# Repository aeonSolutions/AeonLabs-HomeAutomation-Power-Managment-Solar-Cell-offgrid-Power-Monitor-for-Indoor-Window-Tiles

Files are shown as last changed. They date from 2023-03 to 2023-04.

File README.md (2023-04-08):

[PCB-Prototyping-Catalogue](https://github.com/aeonSolutions/PCB-Prototyping-Catalogue)  >>  [Home-Automation](https://github.com/aeonSolutions/PCB-Prototyping-Catalogue/tree/main/Home-Automation)  >>  [Smart Home Solar Power Management](https://github.com/aeonSolutions/PCB-Prototyping-Catalogue/tree/main/Home-Automation/Smart%20Home%20Solar%20Power%20Management)  >>   Solar Cell Tiles Power Monitor for Indoor Windows

<br>


  
 
 

<a href="https://trackgit.com">
trackgit-views
</a>


<br />

# Solar Cell Tiles Power Monitor for Indoor Windows

This is a simple PCB for a direct fit on commercially available [blue solar cell tiles](https://s.click.aliexpress.com/e/_DCnJW0V)  with dimensions 124x124mm. This Smart Device is intended to connected with the [Single Solar Cell with one 18650 Battery Storage](https://github.com/aeonSolutions/AeonLabs-HomeAutomation-Power-Managment-Single-SolarCELL-18650-battery-storage/blob/main/README.md) and also the [Single Solar Cell with two 18650 as Battery Storage](https://github.com/aeonSolutions/AeonLabs-HomeAutomation-Power-Managment-Single-SolarCELL-2X-18650-battery-storage/blob/main/README.md) to do active solar cell tile and battery management up to 8 solar tiles conencted together intended for indoor usage. In particular to be installed on the top or downside of transparent glass windows at a home or office. This PCB, when assembled with a blue solar cell tile, can be used to power a low voltage 4.2V indoor illumination network using ultra-low power micro LED strips.  For insatnce [this one](https://s.click.aliexpress.com/e/_DCKg9xJ) sold on AliExpress.   

When connected in series and installed on several windows and networked, can power off the grid a 4.2V LED illumination on all rooms and compartments at a home or office. During evenings and at night until bedtime. If one intends to use it to power indoors LED illumination during the day is required a High Capacity Power Bank connected to all first tiles of all the series. For instance this [power bank](https://s.click.aliexpress.com/e/_Ddl7nsh) here. 

One important take way about this prototype project is in the ability to be installed on any traditional apartment or home in a big city, requiring  124mm of window glass estate, at the top or at the bottom. And it can connect to existing home automation network or systems. 

<p align="center">
<a href="https://s.click.aliexpress.com/e/_DCnJW0V">

</a>
</p>

A breif view of specifications:

- up to 8 solar cell tiles battery active monitoring 
- Buzzer for sound alarm and warnings
- Onboard Temperature and humidity sensores
- Onboard motion sensor
- PCB asssembly in series made with a 10 pin pin header/ socket. For "plug and play" type of instalations
- Screw terminal to connect main low power 5V DC line at home/office. 

<br>

**Status**

waiting to be tested. Stay tuned for updates.

<br>

## PCB

<p align="center">
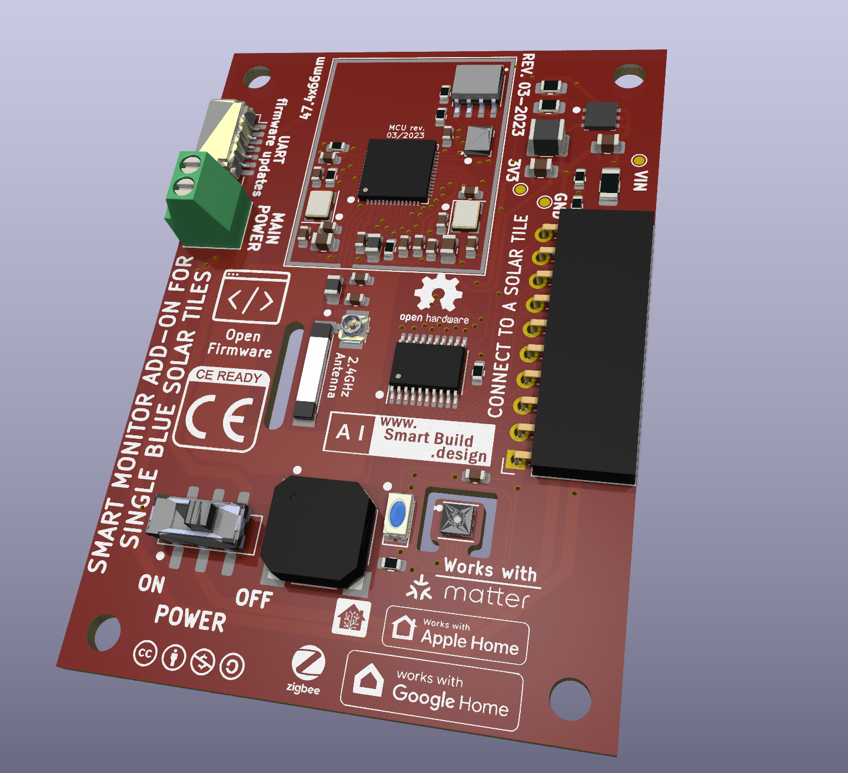
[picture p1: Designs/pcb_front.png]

</p>

<br>

## Compatibility

<p align="center">
 <a href"https://www.apple.com/shop/accessories/all/homekit">

 </a>
<a href="https://home.google.com"> 
 
 </a>
<a href="https://www.home-assistant.io">  
 
 </a>
<a href="https://csa-iot.org/all-solutions/matter/">  
 
 </a>
<a href="https://csa-iot.org/all-solutions/matter/">  
 
 </a>
</p>

<br>

## What one additionally needs
-  home tools
-  [transparent double sided tape](https://s.click.aliexpress.com/e/_DDJxMmD)
-  [blue solar cell tiles](https://s.click.aliexpress.com/e/_DCnJW0V)
-  [ultra-low power micro LED strips](https://s.click.aliexpress.com/e/_DCKg9xJ) 
-  [ultra-low power  LED Cob strips](https://s.click.aliexpress.com/e/_DnqkC4N)
-  [Nylon Guide for Electric Cable](https://s.click.aliexpress.com/e/_DBc1oVX)
-  [NCR18650B 3.7V 3400 mah 18650 Lithium](https://s.click.aliexpress.com/e/_DCh1sw1)
-  [Low power electrical wire](https://s.click.aliexpress.com/e/_DB1T3eN)
-  [16A Electrical Plug Wall Socket 110~250V Dual USB 2000mA Port](https://s.click.aliexpress.com/e/_DlVz3sh)
-  [Soldering iron](https://s.click.aliexpress.com/e/_DnDN8x3)
-  [Solder](https://s.click.aliexpress.com/e/_DlXtKMN)
- [power bank](https://s.click.aliexpress.com/e/_Ddl7nsh) 

<br />
<br />

## Author

You can get in touch with me on my LinkedIn Profile:

#### Miguel Tomas



You can also follow my GitHub Profile to stay updated about my latest projects: 

<br>

### Be supportive of my dedication and work towards technology education and buy me a cup of coffee
The PCB Desgin Files i provide here for anyone to use are free. If you like this Smart Device or use it, please consider buying me a cup of coffee, a slice of pizza or a book to help me study, eat and think new PCB design files.

[](https://www.buymeacoffee.com/migueltomas)

<br />

### Make a donation on Paypal
Make a donation on paypal and get a TAX refund*.

(http://paypal.me/mtpsilva)

<br>

### Support all these open hardware projects and become a patreon  
Liked any of my PCB KiCad Designs? Help and Support my open work to all by becomming a LDAD Patreon.
In return I will give a free PCB design in KiCad to all patreon supporters. To learn more go to patreon.com. Link below.

(https://www.patreon.com/ldad)

<br />
<br />

______________________________________________________________________________________________________________________________
### License
Before proceeding to download any of AeonLabs software solutions for open-source development and/or PCB hardware electronics development make sure you are choosing the right license for your project. See [AeonLabs Solutions for Open Hardware & Source Development](https://github.com/aeonSolutions/PCB-Prototyping-Catalogue/wiki/AeonLabs-Solutions-for-Open-Hardware-&-Source-Development) for more information.

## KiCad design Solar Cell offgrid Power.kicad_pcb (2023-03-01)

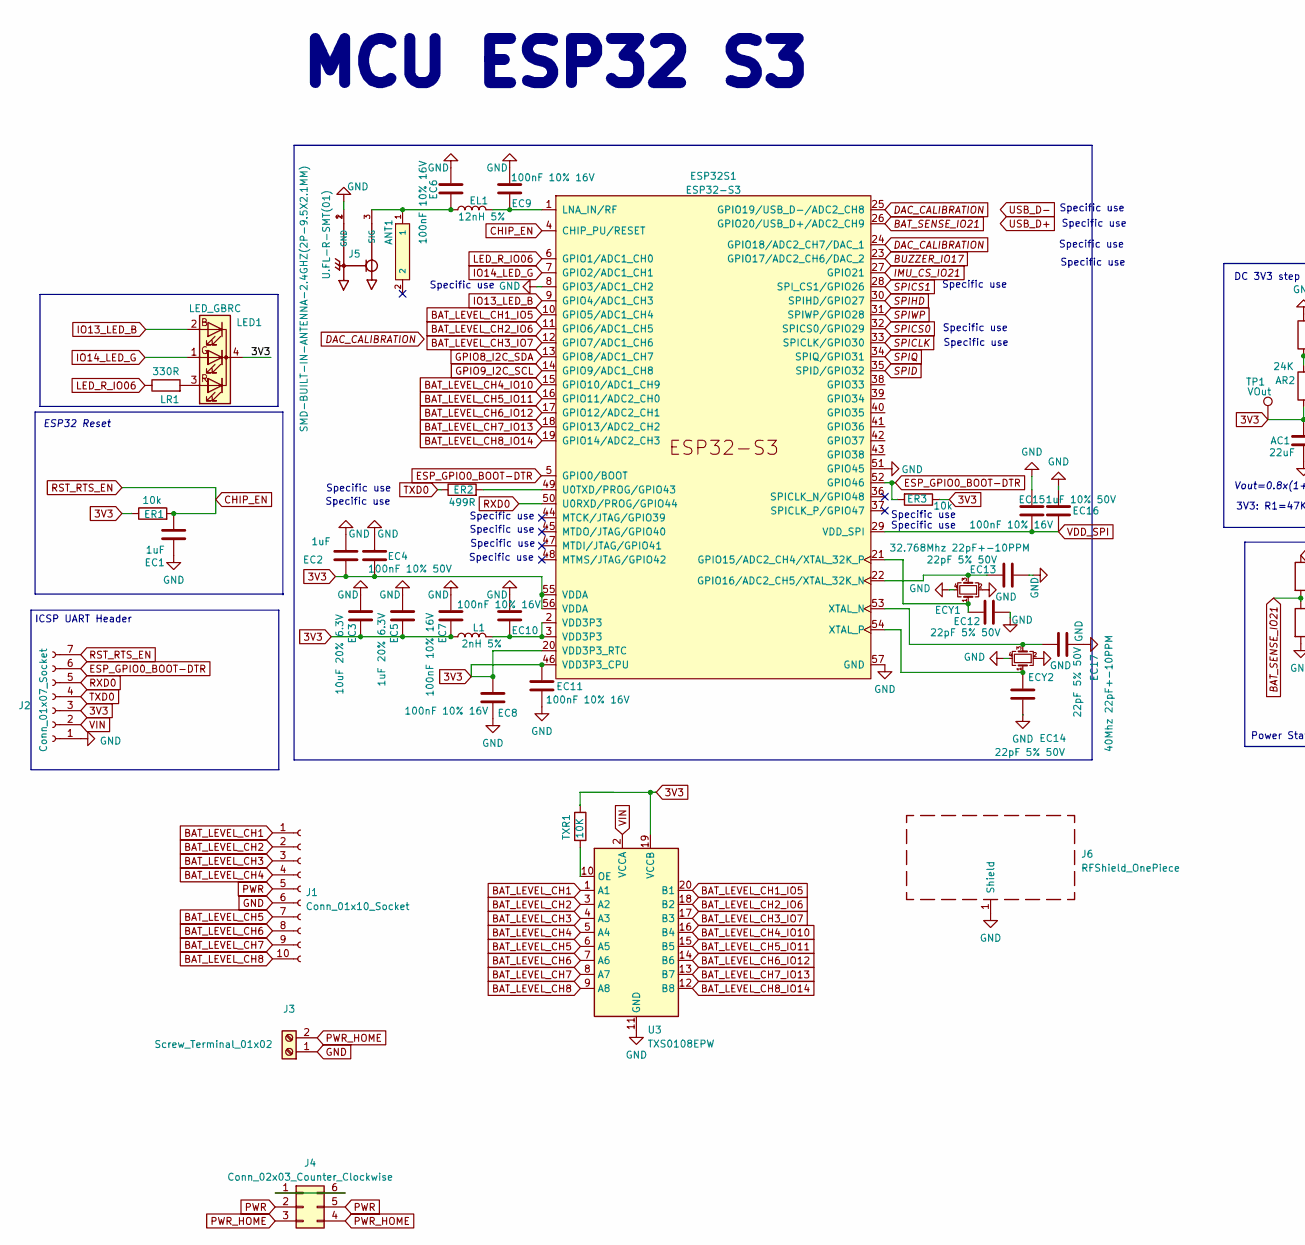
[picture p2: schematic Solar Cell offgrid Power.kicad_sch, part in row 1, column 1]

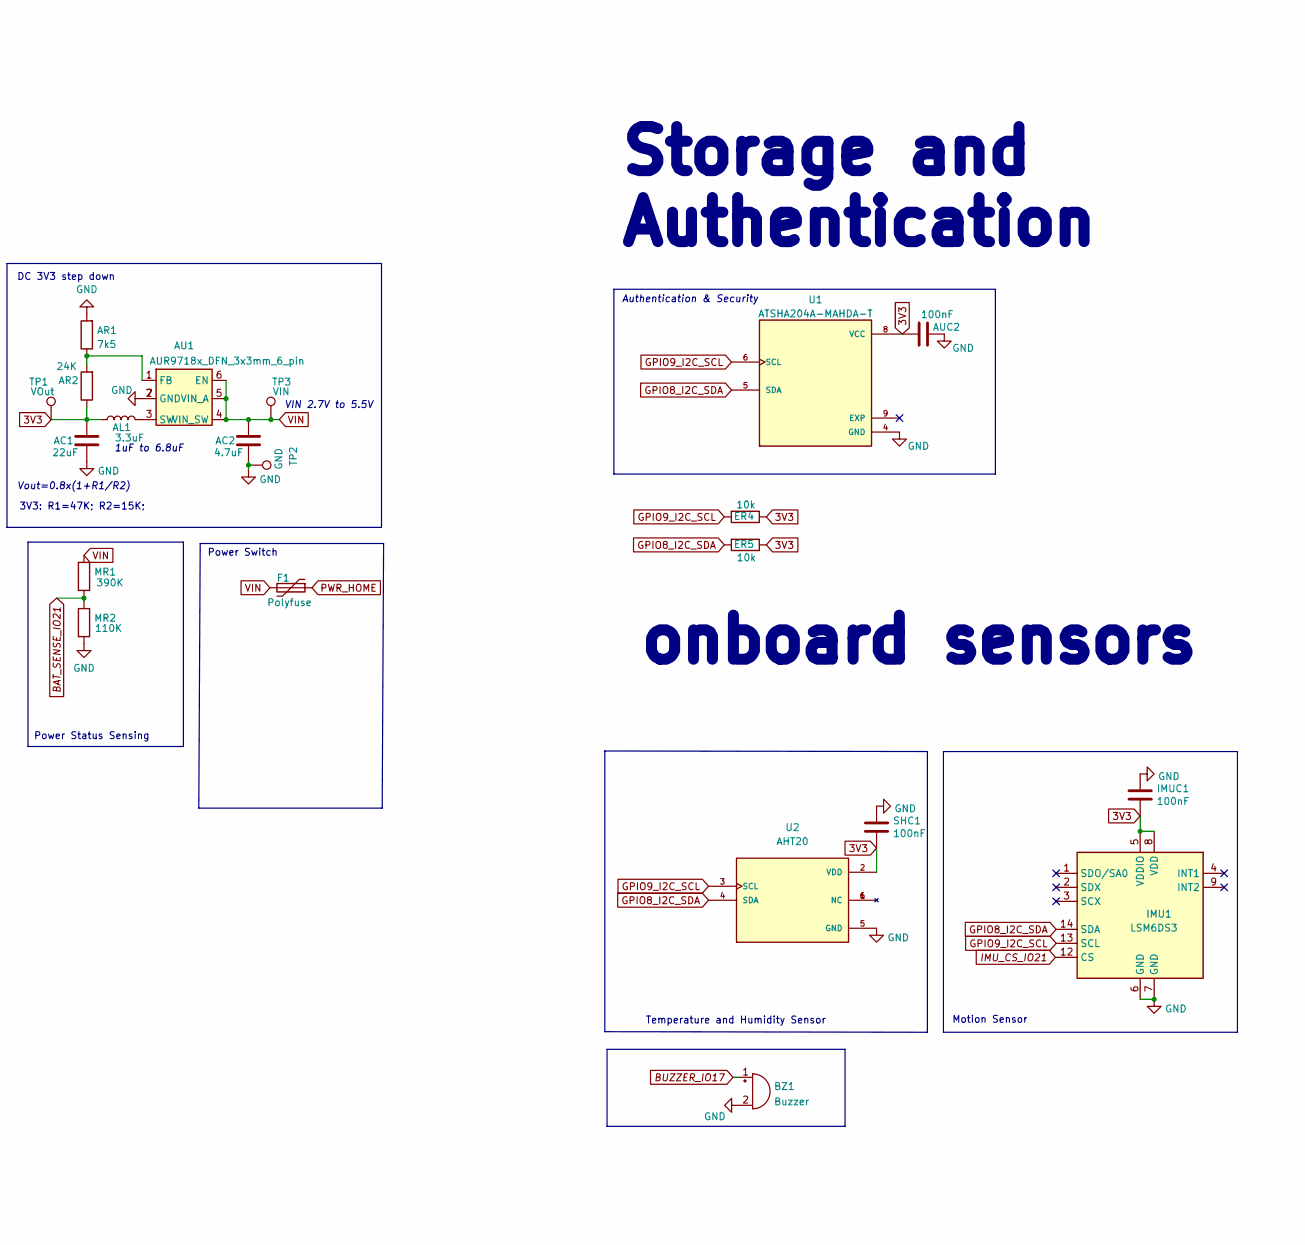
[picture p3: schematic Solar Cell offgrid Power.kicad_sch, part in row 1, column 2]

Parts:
AC1: 22uF; C_0805_2012Metric_Pad1.18x1.45mm_HandSolder
AC2: 4.7uF; C_0805_2012Metric_Pad1.18x1.45mm_HandSolder
AL1: 3.3uF; L_1210_3225Metric
ANT1: SMD-BUILT-IN-ANTENNA-2.4GHZ(2P-9.5X2.1MM); 2.4ghZ WIFI ANTENNA AN9520_ANT2-SMD-9.5X2.1X1.0MM
AR1: 7k5; R_0805_2012Metric_Pad1.20x1.40mm_HandSolder
AR2: 24K; R_0805_2012Metric_Pad1.20x1.40mm_HandSolder
AU1: AUR9718x_DFN_3x3mm_6_pin; AUR9718 ST1S09 SON95P300X300X100-7N
AUC2: 100nF; C_0603_1608Metric
BZ1: Buzzer; MagneticBuzzer_Kobitone_254-EMB84Q-RO
EC1: 1uF; C_0603_1608Metric
EC2: 1uF; C_0805_2012Metric
EC3: 10uF 20% 6.3V; C_0805_2012Metric
EC4: 100nF 10% 50V; C_0603_1608Metric
EC5: 1uF 20% 6.3V; C_0603_1608Metric
EC6, EC7, EC8, EC9, EC10, EC11, EC15: 100nF 10% 16V; C_0603_1608Metric
EC12, EC13, EC14, EC17: 22pF 5% 50V; C_0603_1608Metric
EC16: 1uF 10% 50V; C_0603_1608Metric
ECY1: 32.768Mhz 22pF+-10PPM; Crystal_SMD_EuroQuartz_MT-4Pin_3.2x2.5mm
ECY2: 40Mhz 22pF+-10PPM; Crystal_SMD_EuroQuartz_MT-4Pin_3.2x2.5mm
EL1: 12nH 5%; L_0805_2012Metric
ER1, ER3, ER4, ER5: 10k; R_0603_1608Metric
ER2: 499R; R_0603_1608Metric
ESP32S1: ESP32-S3; QFN-56-1EP_7x7mm_P0.4mm_EP5.6x5.6mm
F1: Polyfuse; Fuse_1206_3216Metric_Pad1.42x1.75mm_HandSolder
IMU1: LSM6DS3; LSM6DS3 Motion Sensor PQFN50P300X250X86-14N
IMUC1: 100nF; C_0603_1608Metric
J1: Conn_01x10_Socket; PinSocket_1x10_P2.54mm_Horizontal
J2: Conn_01x07_Socket; JST_SH_SM07B-SRSS-TB_1x07-1MP_P1.00mm_Horizontal
J3: Screw_Terminal_01x02; TerminalBlock_Phoenix_MPT-0,5-2-2.54_1x02_P2.54mm_Horizontal
J4: Conn_02x03_Counter_Clockwise; Toggle Switch 2 pos PCB MSS-22D18G2 2P2T
J5: U.FL-R-SMT(01); RF Antenna IPEX SMD PCB HRS_U.FL-R-SMT(01)
J6: RFShield_OnePiece; ESP32-S3 GND Shield
L1: 2nH 5%; L_0805_2012Metric
LED1: LED_GBRC; LED_1206_3210_RGB_Metric
LR1: 330R; R_0603_1608Metric
MR1: 390K; R_0603_1608Metric
MR2: 110K; R_0603_1608Metric
SHC1: 100nF; C_0603_1608Metric
TP1: VOut; TestPoint_Pad_D1.0mm
TP2: GND; TestPoint_Pad_D1.0mm
TP3: VIN; TestPoint_Pad_D1.0mm
TXR1: 10K; R_0603_1608Metric
U1: ATSHA204A-MAHDA-T; ATSHA204A Auth SOIC8; PART_REV A
U2: AHT20; AHT20 HT Sensor PSON100P300X300X110-6N; PARTREV V1.0
U3: TXS0108EPW; TSSOP-20_4.4x6.5mm_P0.65mm

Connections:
3V3: AC1.1, AL1.1, AR2.1, EC2.2, EC3.1, EC4.2, EC5.1, EC7.1, EC8.1, EC11.1, ER1.1, ER3.1, ER4.1, ER5.1, ESP32S1.20 (VDD3P3_RTC), ESP32S1.46 (VDD3P3_CPU), ESP32S1.55 (VDDA), ESP32S1.56 (VDDA), IMU1.5 (VDDIO), IMU1.8 (VDD), IMUC1.2, J2.3, L1.1, LED1.4 (K), SHC1.2, TP1.1, TXR1.1, U1.8 (VCC), U2.2 (VDD), U3.19 (VCCB)
BAT_LEVEL_CH1: J1.1, U3.1 (A1)
BAT_LEVEL_CH1_IO5: ESP32S1.10 (GPIO5/ADC1_CH4), U3.20 (B1)
BAT_LEVEL_CH2: J1.2, U3.3 (A2)
BAT_LEVEL_CH2_IO6: ESP32S1.11 (GPIO6/ADC1_CH5), U3.18 (B2)
BAT_LEVEL_CH3: J1.3, U3.4 (A3)
BAT_LEVEL_CH3_IO7: ESP32S1.12 (GPIO7/ADC1_CH6), U3.17 (B3)
BAT_LEVEL_CH4: J1.4, U3.5 (A4)
BAT_LEVEL_CH4_IO10: ESP32S1.15 (GPIO10/ADC1_CH9), U3.16 (B4)
BAT_LEVEL_CH5: J1.7, U3.6 (A5)
BAT_LEVEL_CH5_IO11: ESP32S1.16 (GPIO11/ADC2_CH0), U3.15 (B5)
BAT_LEVEL_CH6: J1.8, U3.7 (A6)
BAT_LEVEL_CH6_IO12: ESP32S1.17 (GPIO12/ADC2_CH1), U3.14 (B6)
BAT_LEVEL_CH7: J1.9, U3.8 (A7)
BAT_LEVEL_CH7_IO13: ESP32S1.18 (GPIO13/ADC2_CH2), U3.13 (B7)
BAT_LEVEL_CH8: J1.10, U3.9 (A8)
BAT_LEVEL_CH8_IO14: ESP32S1.19 (GPIO14/ADC2_CH3), U3.12 (B8)
BAT_SENSE_IO21: ESP32S1.26 (GPIO20/USB_D+/ADC2_CH9), MR1.2, MR2.1
BUZZER_IO17: BZ1.1 (-), ESP32S1.23 (GPIO17/ADC2_CH6/DAC_2)
CHIP_EN: EC1.2, ER1.2, ESP32S1.4 (CHIP_PU/RESET), J2.7
DAC_CALIBRATION: ESP32S1.24 (GPIO18/ADC2_CH7/DAC_1), ESP32S1.25 (GPIO19/USB_D-/ADC2_CH8)
ESP_GPIO0_BOOT-DTR: ER3.2, ESP32S1.5 (GPIO0/BOOT), ESP32S1.52 (GPIO46), J2.6
GND: AC1.2, AC2.2, AR1.2, AU1.2 (GND), AU1.7 (GND), BZ1.2 (+), EC1.1, EC2.1, EC3.2, EC4.1, EC5.2, EC6.2, EC7.2, EC8.2, EC9.2, EC10.2, EC11.2, EC12.2, EC13.2, EC14.2, EC17.2, ECY1.2, ECY1.4, ECY2.2, ECY2.4, ESP32S1.8 (GPIO3/ADC1_CH2), ESP32S1.51 (GPIO45), ESP32S1.57 (GND), IMU1.6 (GND), IMU1.7 (GND), IMUC1.1, J1.6, J2.1, J3.1, J5.1 (GND), J5.2 (GND), J6.1 (Shield), MR2.2, SHC1.1, TP2.1, U1.4 (GND), U2.5 (GND), U3.11 (GND)
GPIO8_I2C_SDA: ER5.2, ESP32S1.13 (GPIO8/ADC1_CH7), IMU1.14 (SDA), U1.5 (SDA), U2.4 (SDA)
GPIO9_I2C_SCL: ER4.2, ESP32S1.14 (GPIO9/ADC1_CH8), IMU1.13 (SCL), U1.6 (SCL), U2.3 (SCL)
IMU_CS_IO21: ESP32S1.27 (GPIO21), IMU1.12 (CS)
IO13_LED_B: ESP32S1.9 (GPIO4/ADC1_CH3), LED1.2 (BA)
IO14_LED_G: ESP32S1.7 (GPIO2/ADC1_CH1), LED1.1 (GA)
LED_R_IO06: ESP32S1.6 (GPIO1/ADC1_CH0), LR1.1
unnamed: AR1.1, AR2.2, AU1.1 (FB)
unnamed: AL1.2, AU1.3 (SW)
unnamed: EC10.1, ESP32S1.2 (VDD3P3), ESP32S1.3 (VDD3P3), L1.2
unnamed: EC12.1, ECY1.1, ESP32S1.21 (GPIO15/ADC2_CH4/XTAL_32K_P)
unnamed: EC13.1, ECY1.3, ESP32S1.22 (GPIO16/ADC2_CH5/XTAL_32K_N)
unnamed: EC9.1, EL1.2, ESP32S1.1 (LNA_IN/RF)
unnamed: ER2.2, ESP32S1.49 (U0TXD/PROG/GPIO43)
unnamed: EC17.1, ECY2.3, ESP32S1.53 (XTAL_N)
unnamed: EC14.1, ECY2.1, ESP32S1.54 (XTAL_P)
unnamed: J4.1, J4.6
unnamed: ANT1.1, EC6.1, EL1.1, J5.3 (SIG)
unnamed: LED1.3 (RA), LR1.2
unnamed: TXR1.2, U3.10 (OE)
PWR: J1.5, J4.2, J4.5
PWR_HOME: F1.1, J3.2, J4.3, J4.4
RXD0: ESP32S1.50 (U0RXD/PROG/GPIO44), J2.5
SPICLK: ESP32S1.33 (SPICLK/GPIO30)
SPICS0: ESP32S1.32 (SPICS0/GPIO29)
SPICS1: ESP32S1.28 (SPI_CS1/GPIO26)
SPID: ESP32S1.35 (SPID/GPIO32)
SPIHD: ESP32S1.30 (SPIHD/GPIO27)
SPIQ: ESP32S1.34 (SPIQ/GPIO31)
SPIWP: ESP32S1.31 (SPIWP/GPIO28)
TXD0: ER2.1, J2.4
VDD_SPI: EC15.1, EC16.1, ESP32S1.29 (VDD_SPI)
VIN: AC2.1, AU1.4 (VIN_SW), AU1.5 (VIN_A), AU1.6 (EN), F1.2, J2.2, MR1.1, TP3.1, U3.2 (VCCA)

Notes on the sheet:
Specific use
Vout=0.8x(1+R1/R2)
onboard sensors
3V3: R1=47K; R2=15K;
Power Status Sensing
DC 3V3 step down
ESP32 Reset
Authentication & Security
Storage and Authentication
VIN 2.7V to 5.5V
Temperature and Humidity Sensor
Power Switch
ICSP UART Header
1uF to 6.8uF
MCU ESP32 S3
Motion Sensor

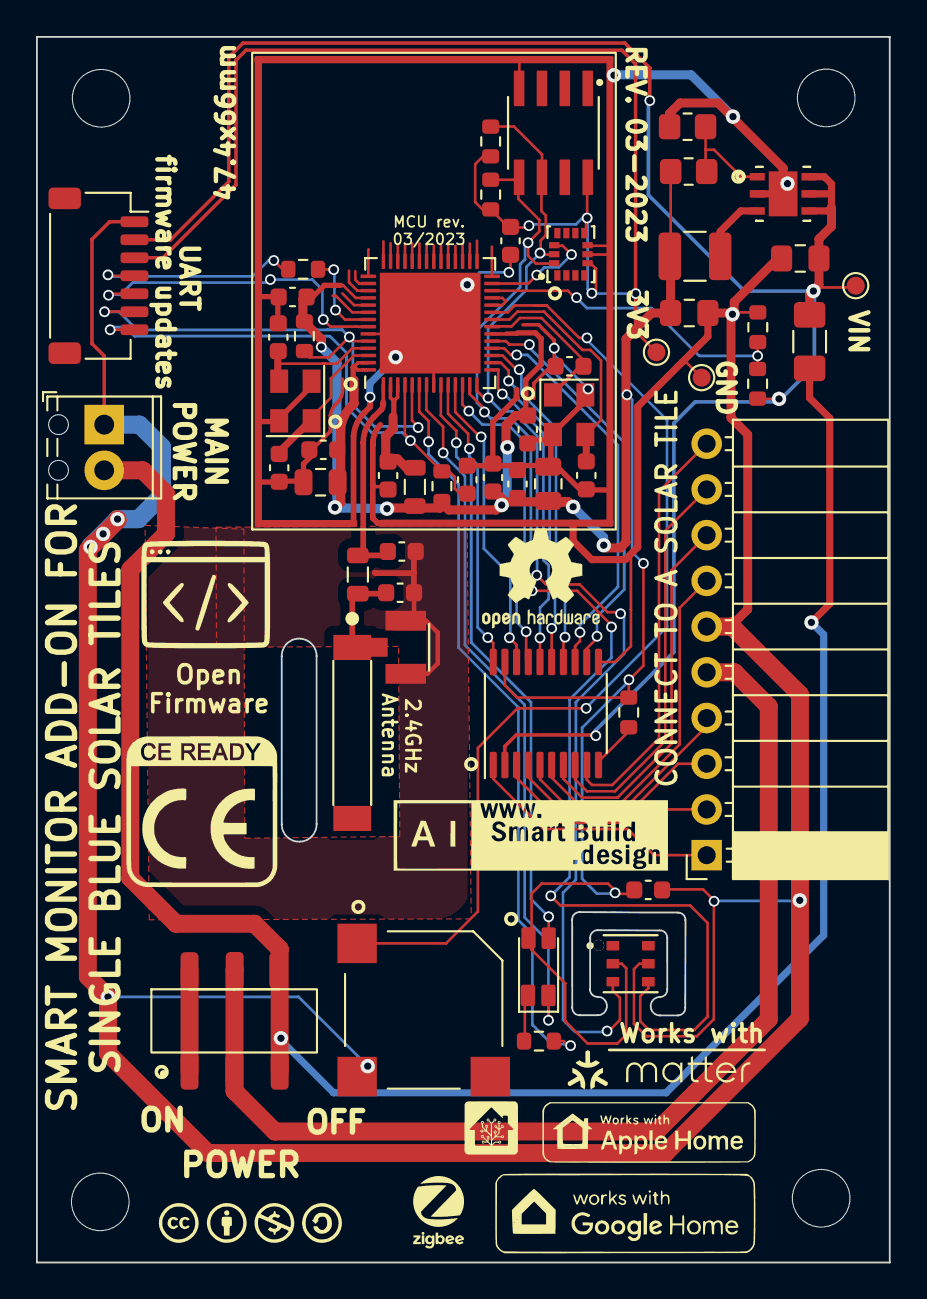
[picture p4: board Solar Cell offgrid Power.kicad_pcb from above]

Board: 2 copper layers, 47.4 x 68.1 mm, 54 parts (0 on the bottom side), 47 nets.
